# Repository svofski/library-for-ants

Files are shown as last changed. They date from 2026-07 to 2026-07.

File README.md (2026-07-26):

Library for ants
================
Robotic microSD card changer that wants to be a tape robot when it grows up

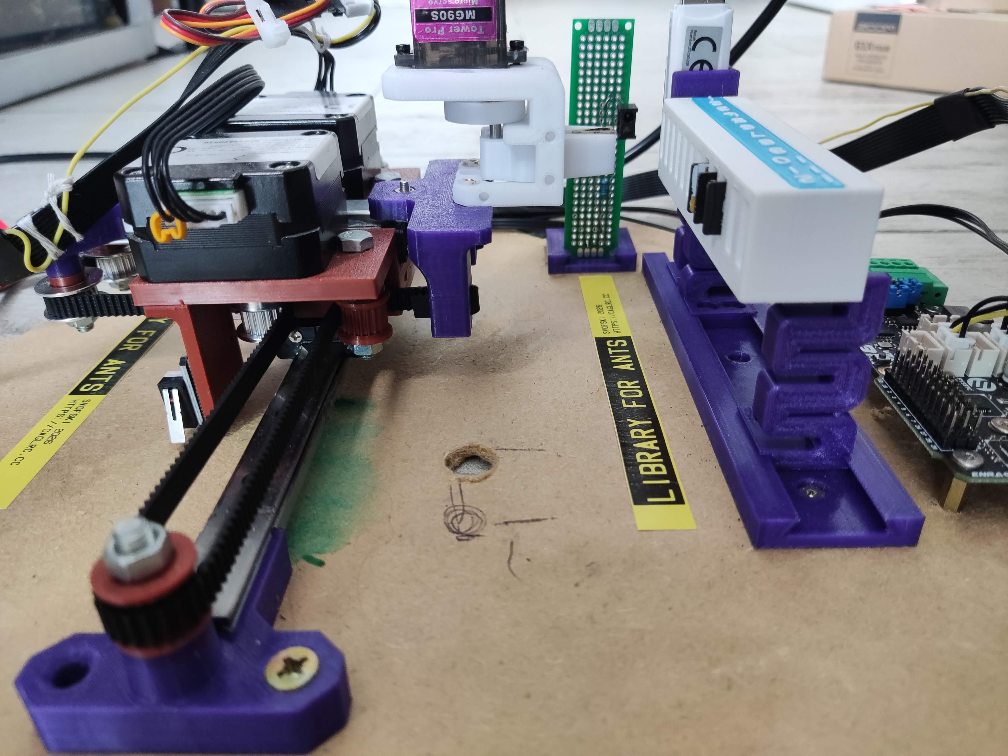
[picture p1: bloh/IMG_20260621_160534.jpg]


It's a microSD card changer. 

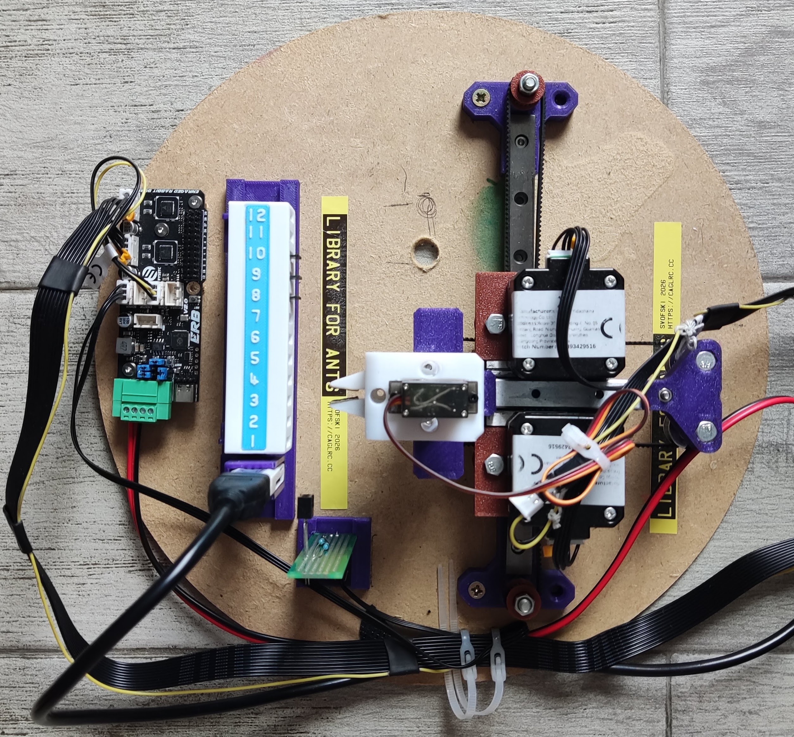
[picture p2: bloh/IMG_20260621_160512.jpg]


It can pick and insert one out of 12 cards in the magazine into a fixed microSD card reader.

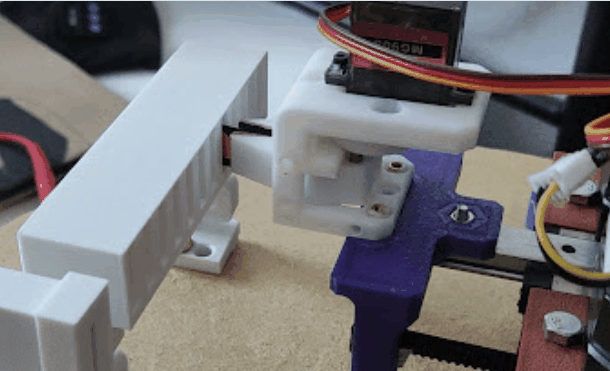
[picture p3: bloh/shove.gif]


The SD card is held using GRIPOR, which is an interesting project in itself.



GRIPOR
------
The gripper design files are [here](gripor)
There are two Gripors: the pliers version (used in Library for ants) and the parallel version. Both are tested and working.

Mechanics
---------
The mechanical parts are designed in FreeCAD. All CAD files are in the [cad](cad) folder.

Robotnik
--------
ERB firmware runs unmodified Klipper. The control program is written in Python using Textual. 
Some setup is needed to configure a fresh Linux to work with Klipper. 
The scripts are in the [scripts](scripts) directory. 

From experience, every distro needs a bit of persuasion them to work so they're only provided as hints.

Acknowledgements
----------------

**Library for ants** would not be possible without previous work of other people to whom I owe my deepest respect.

Links to other projects that I borrwed ideas from:
 * https://www.buildlog.net/blog/2017/10/the-midtbot-a-new-flavor-of-h-bot/
 * https://github.com/bdring/midTbot_esp32
 * https://www.klipper3d.org/
 * https://textual.textualize.io/

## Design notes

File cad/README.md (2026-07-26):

T-bot design files
==================

Printables
----------
All parts ready to print: [middleT-project.3mf](/cad/printables/middleT-project.3mf)

Design files
------------
FreeCAD doesn't make it easy to keep track of changes and interdependencies. I apologise if something is missing. 

Everything is built around linear rails with MGN12H blocks.

### X axis ends

End mount also functions as a physical stop for the Y axis when homing.

[xaxis-end.FCStd](xaxis-end.FCStd)

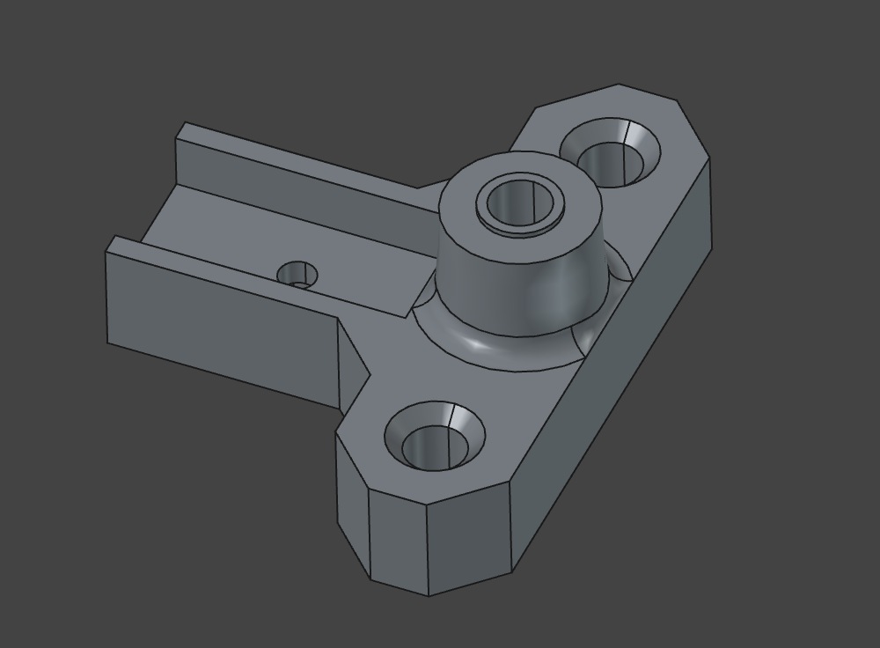
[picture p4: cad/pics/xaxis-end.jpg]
xaxis-end


### Y axis ends

The back side holds pulleys,

[yaxis-frontside.FCStd](yaxis-frontside.FCStd)

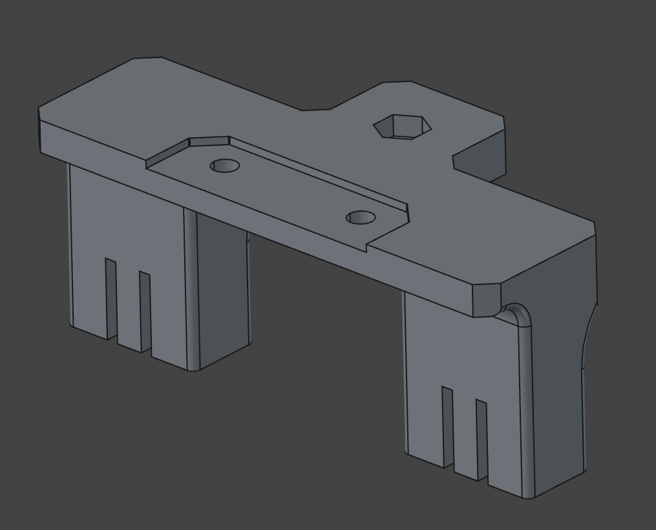
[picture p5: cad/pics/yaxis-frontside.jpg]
yaxis-frontside


[yaxis-backside-v2.FCStd](yaxis-backside-v2.FCStd)

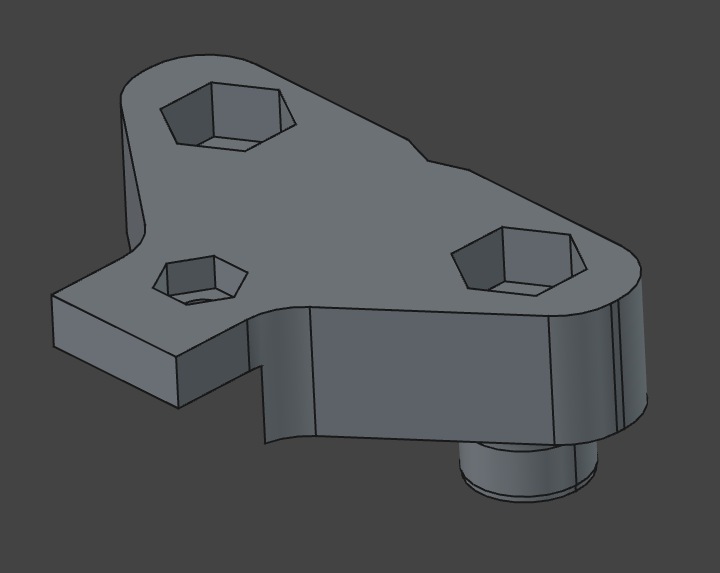
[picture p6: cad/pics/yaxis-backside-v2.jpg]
yaxis-backside-v2


### Middle T assembly

Middle T is a complex part that comprises two dovetailed pieces that ahold MGN12H sliders, two NEMA17 stepper motors and 2 additional pulleys.

[middlet-2.FCStd](middlet-2.FCStd)
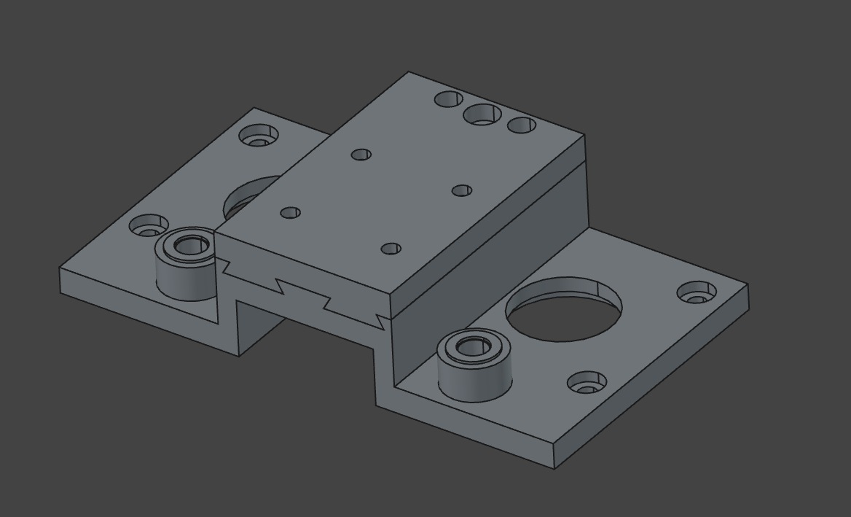
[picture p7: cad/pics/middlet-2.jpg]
middlet

(pictured upside down)

### Storage

This file has the magazine, magazine legs, usb reader leg and the bottom rail.

[usb-reader-adapter1.FCStd](usb-reader-adapter1.FCStd)

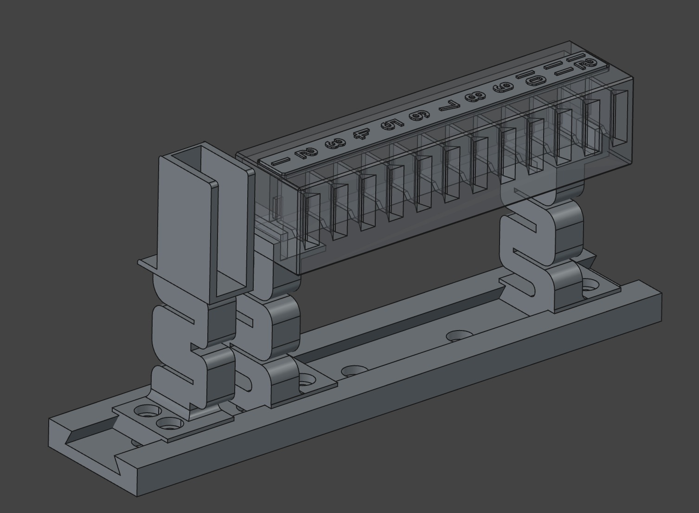
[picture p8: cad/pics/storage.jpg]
storage


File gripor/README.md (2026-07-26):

GRIPOR
======

Here you can find design files and printables for GRIPOR-pliers and GRIPOR-gears. 
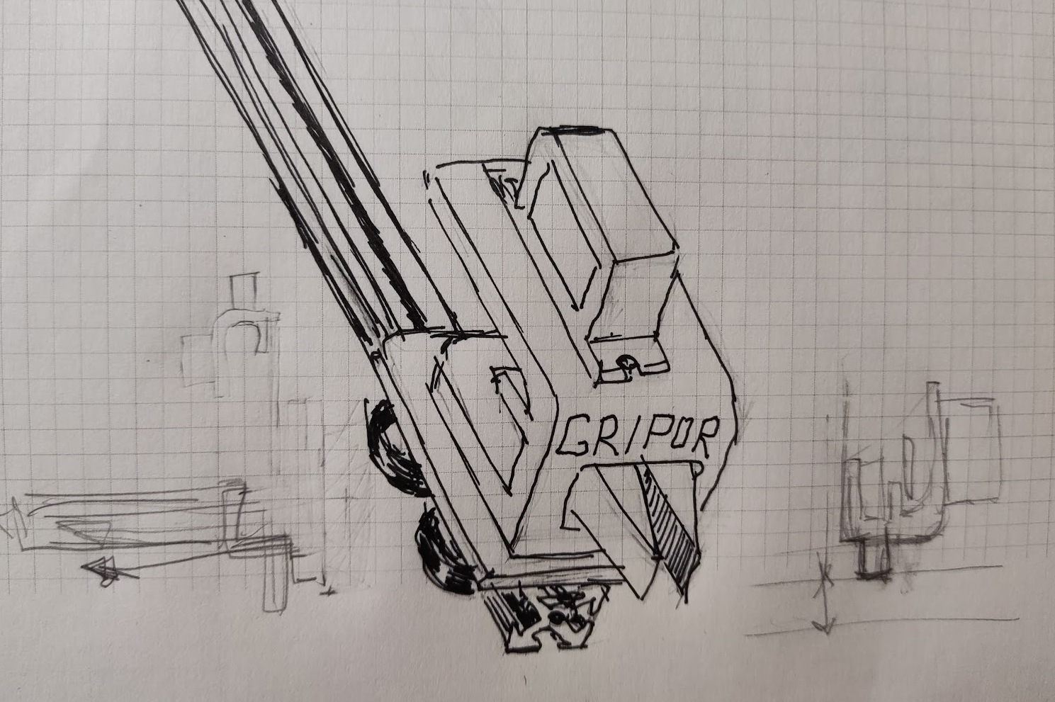
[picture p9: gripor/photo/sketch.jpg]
sketch


They can pinch and hold firmly small objects like microSD cards, or wield a small knife.

Pliers
------

This is the model that looks like a common sprue gripper.

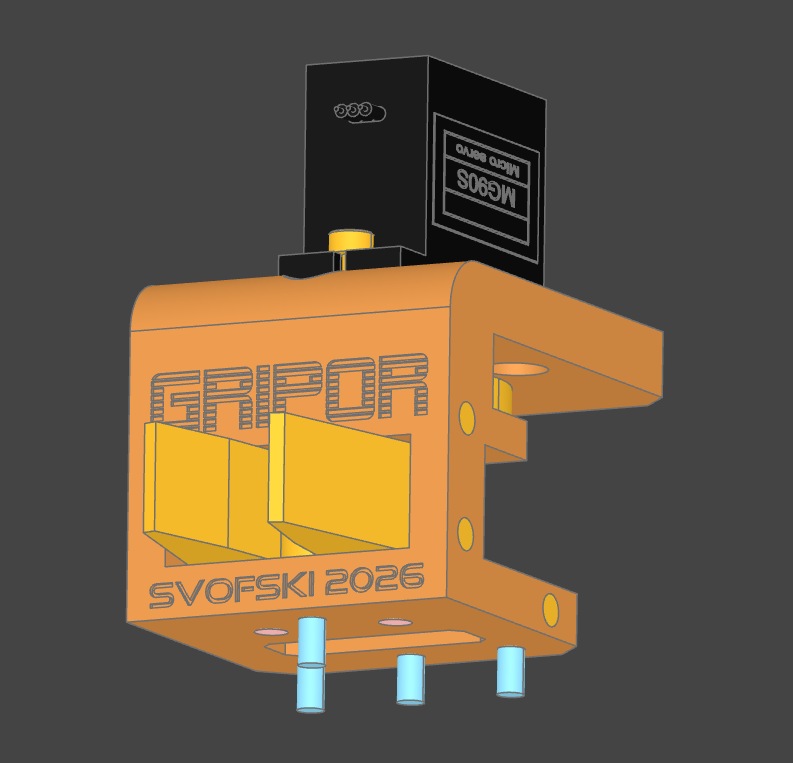
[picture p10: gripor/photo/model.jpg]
pliers-model

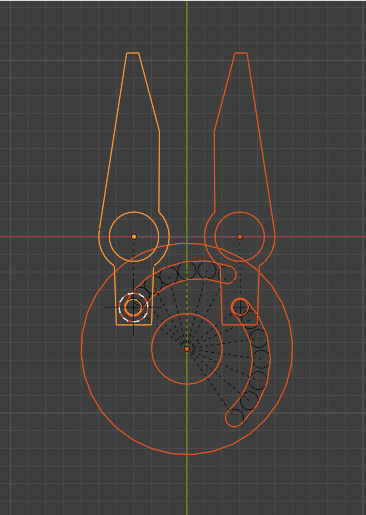
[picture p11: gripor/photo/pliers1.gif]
pliers-diagram

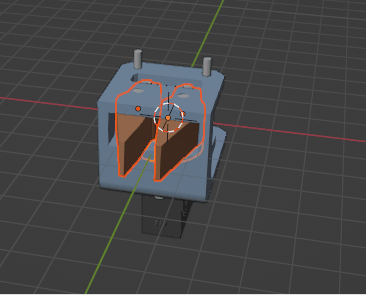
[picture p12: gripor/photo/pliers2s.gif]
pliers-3d


Extra hardware needed:

 * 4x bearings 3x6x2.5 (ID-OD-thickness)
 * 4x 3mm dia round pins approx 20mm long
 * 2xM2 screws for servo mount (optionally use M2 threaded inserts)
 * M3 threaded inserts optionally recommended for mounting holes
 * 1x MG90S micro servo

Some assembly required

Glue thin pieces of rubber eraser to the inner surfaces of the pliers' tips, it immensely improves the grip.

Gears
-----
This is a parallel gripper. It requires no extra hardware except for the screws. 
It's a good gripper that's easy to build, but it may be a bit less rigid than the pliers version.

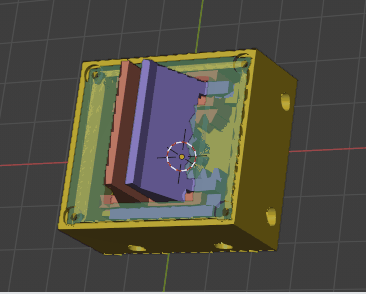
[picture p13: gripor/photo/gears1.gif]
gears-model


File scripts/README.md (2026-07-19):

## Environment setup stuff

### klipper & klippy

sudo apt install git python3-virtualenv python3-dev libffi-dev build-essential libncurses-dev gawk -y
git clone https://github.com/Klipper3d/klipper.git
virtualenv -p python3 ~/klippy-env
~/klippy-env/bin/pip install -r ~/library_for_ants/klipper/scripts/klippy-requirements.txt

### /etc/systemd/system/klipper.service

```
#Systemd service file for klipper
[Unit]
Description=Starts klipper on startup
After=network.target

[Install]
WantedBy=multi-user.target

[Service]
Type=simple
User=svo
RemainAfterExit=yes
ExecStart=/home/svo/klippy-env/bin/python /home/svo/library_for_ants/klipper/klippy/klippy.py /home/svo/library_for_ants/scripts/printer.cfg -l /tmp/klippy.log
Restart=always
RestartSec=10
```

```
sudo systemctl daemon-reload
sudo systemctl enable klipper.service
sudo systemctl start klipper.service
```

### Automount

I had very rough experience across Armbian and Debian. This seems to work on both:
```
sudo cp mnt-robot_media.* /etc/systemd/system/
sudo cp robot-media-watch.timer /etc/systemd/system/
sudo cp robot-media-watch.service /etc/systemd/system/
chmod +x robot-media-check.sh
mkdir /mnt/robot_media
systemctl daemon-reload 
systemctl enable --now mnt-robot_media.automount
systemctl enable --now robot-media-watch.timer
```

### udev hotplug 

Avoid annoying device name changes etc

```
sudo cp 99-klipper-hotplug.rules 99-usb-serial.rules /etc/udev/rules.d/
sudo udevadm control --reload-rules
```

### pythong

pip3 install -r requirements.txt

## References

Kinematics: midTbot

 https://www.buildlog.net/blog/2017/10/the-midtbot-a-new-flavor-of-h-bot/
 https://github.com/bdring/midTbot_esp32

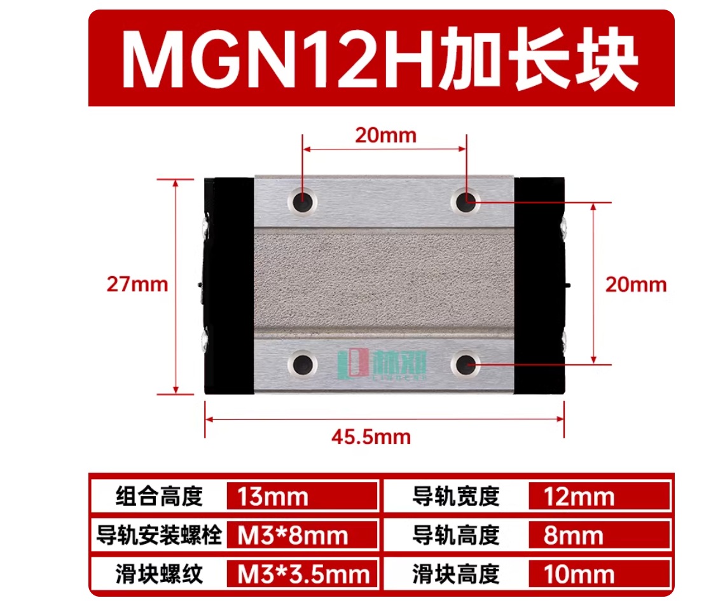
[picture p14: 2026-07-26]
cad/pics/mgn12h-block-dimensions.jpg

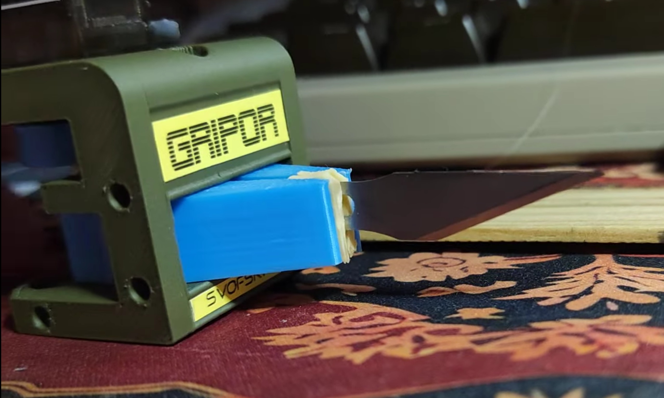
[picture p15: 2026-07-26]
bloh/gripor3.jpg

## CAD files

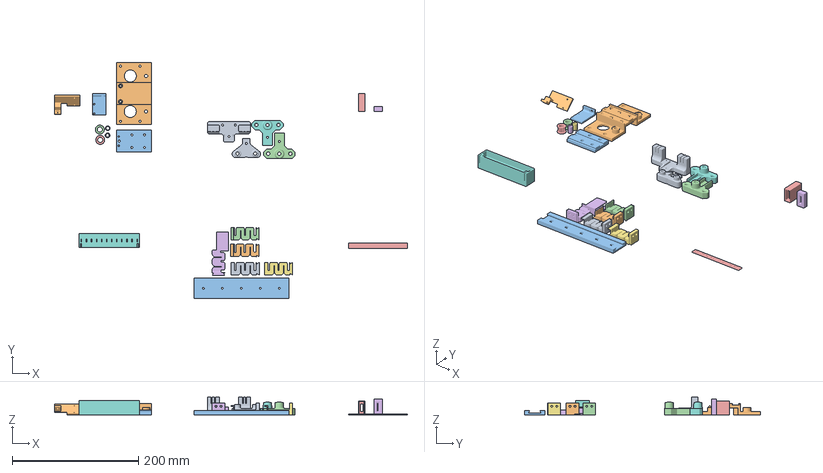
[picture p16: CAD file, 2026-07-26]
cad/printables/middleT-project.3mf
558.2 x 372.8 x 28.0 mm
yaxis-back
gt2-pulley-ID8.stl x 2
xaxis-end x 2
frontside
EndswitchBracketY.step
EndswitchBracketX.step
usb-reader-adapter1-middle-shell.step
usb-reader-adapter1-business-end.step
usb-reader-adapter1-post.step
storage-bay.step
storage-post-left.step
storage-post-right.step x 2
usb-reader-adapter1-storagerail.step
storageindex.step
usb-readerpost-for-vertical.step

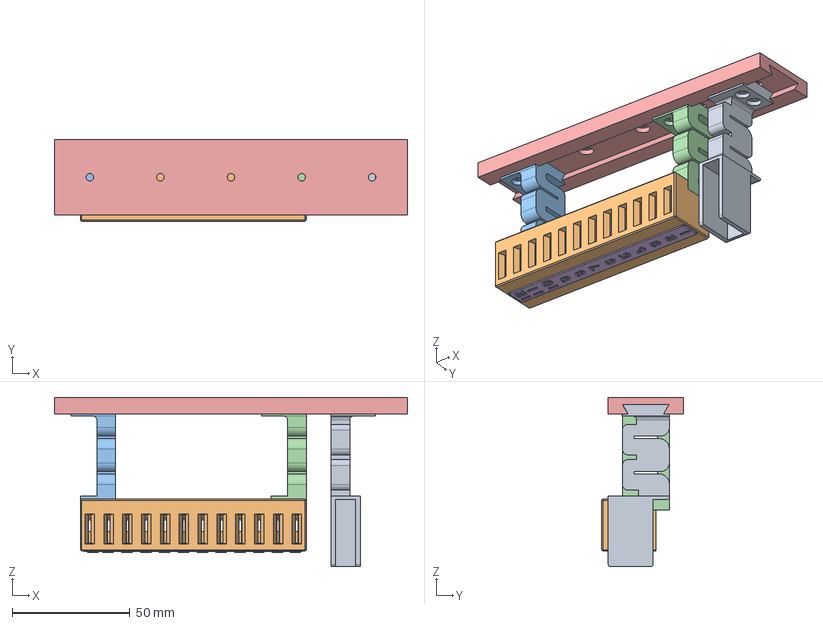
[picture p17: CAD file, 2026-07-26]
cad/usb-reader-adapter1.FCStd
150.0 x 34.7 x 72.0 mm
post-for-vertical
StorageBay
post-left
post-right
rail
index

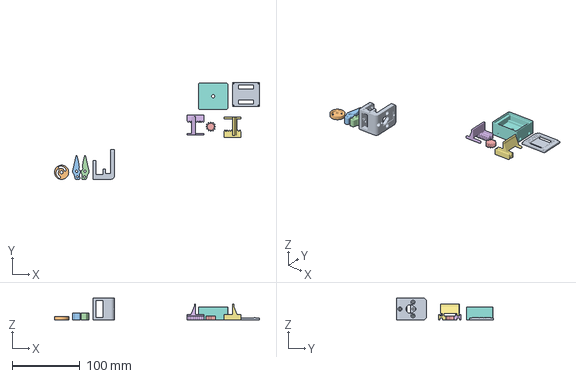
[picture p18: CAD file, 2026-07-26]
gripor/gripor-all.3mf
302.0 x 142.9 x 32.0 mm

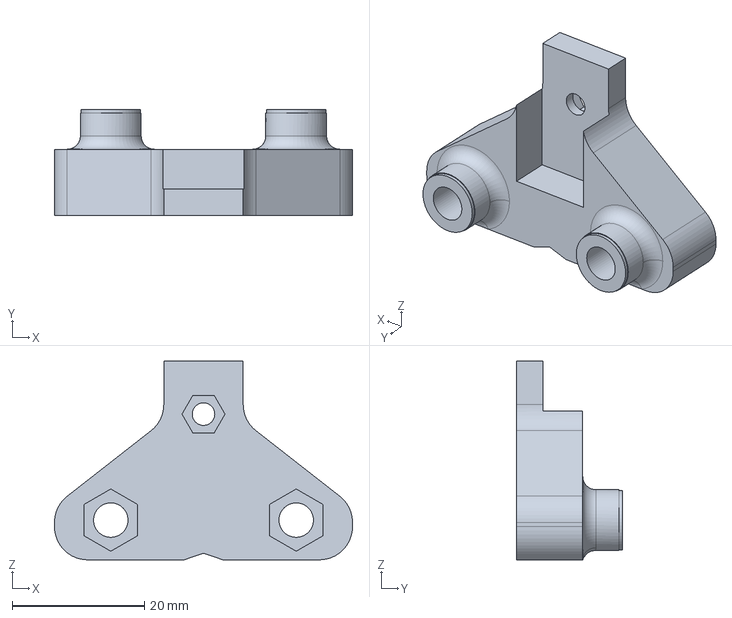
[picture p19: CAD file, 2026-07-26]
cad/yaxis-backside-v2.FCStd
45.0 x 16.0 x 30.0 mm

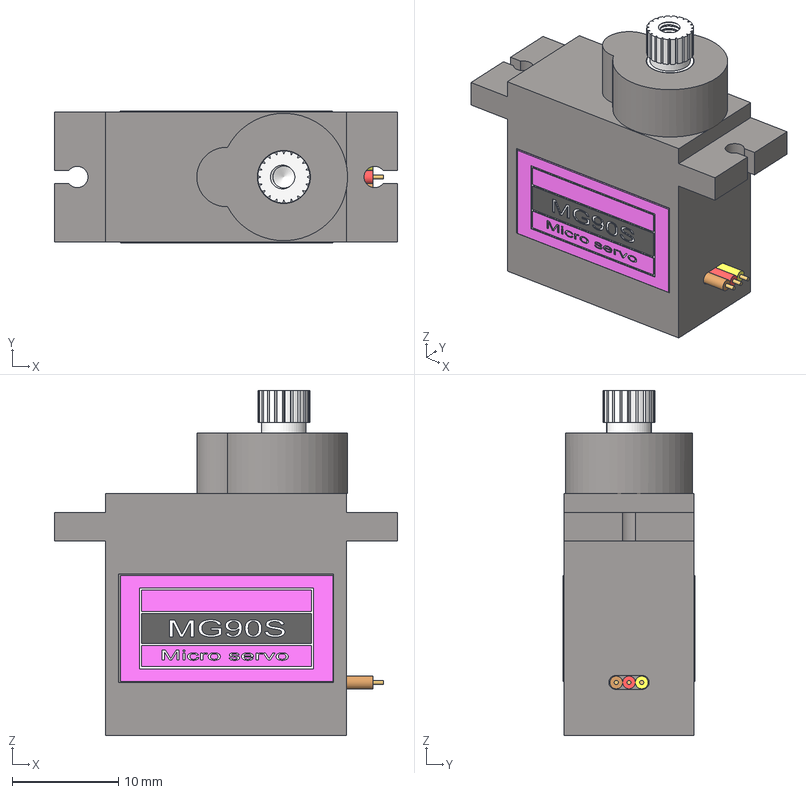
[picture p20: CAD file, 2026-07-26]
gripor/M90S_ali.step
32.3 x 12.4 x 32.5 mm
axe
base001
etiquette
Tube
Cylindre
Tube001
Tube002
etiquette001
Cylindre001
Cylindre002

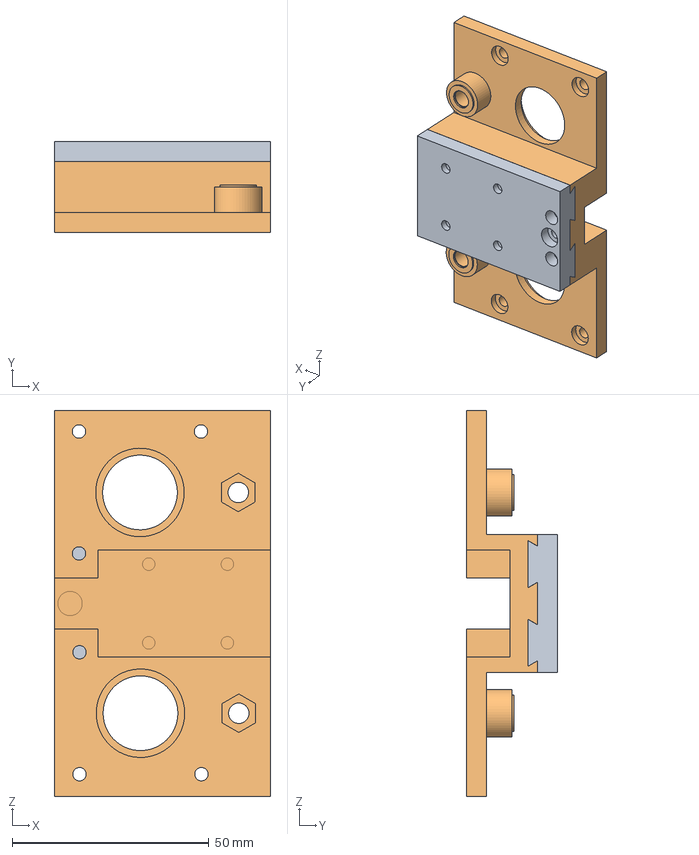
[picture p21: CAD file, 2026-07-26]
cad/middlet-2.FCStd
55.0 x 23.1 x 98.1 mm
MiddleTBottom
MiddleT-Compound

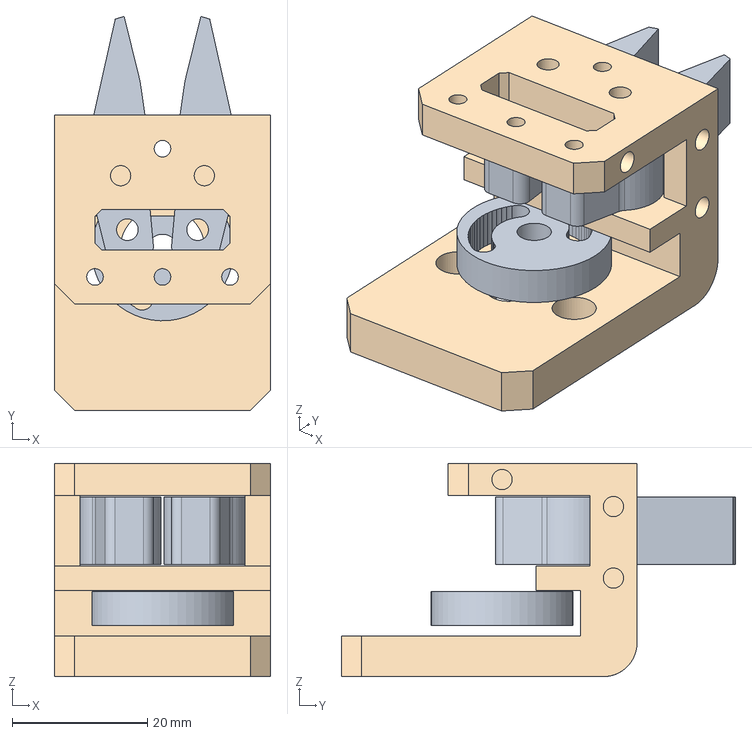
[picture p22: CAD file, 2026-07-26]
gripor/gripor-combined.step
32.0 x 58.4 x 31.6 mm

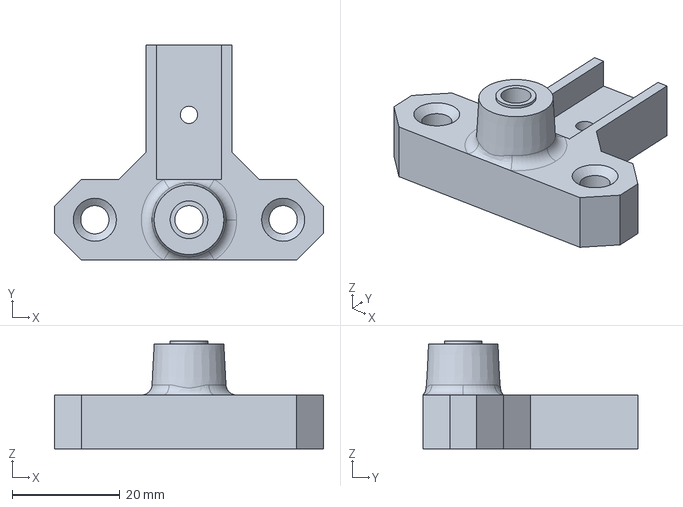
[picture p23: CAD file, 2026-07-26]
cad/xaxis-end.FCStd
50.0 x 40.0 x 20.0 mm

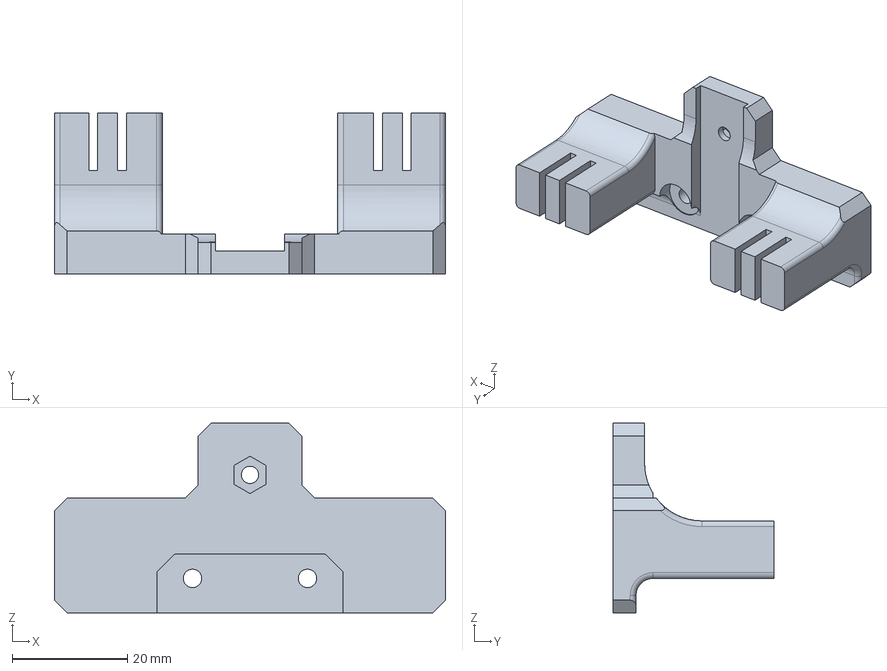
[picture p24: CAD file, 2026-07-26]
cad/yaxis-frontside.FCStd
68.0 x 28.0 x 33.0 mm

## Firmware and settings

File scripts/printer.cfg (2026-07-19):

[mcu]
serial: /dev/ttyERB

[printer]
kinematics: corexy
max_velocity: 300
max_accel: 800 #250
square_corner_velocity: 1
max_z_velocity: 10
max_z_accel: 100

[stepper_x]
step_pin: gpio10
dir_pin: gpio9
enable_pin: !gpio8
microsteps: 16
rotation_distance: 40
#endstop_pin: ^gpio24
position_endstop: 0
position_max: 210

# sensorless homing
endstop_pin: tmc2209_stepper_x:virtual_endstop
homing_speed: 35
homing_retract_dist: 0

[tmc2209 stepper_x]
uart_pin: gpio11
diag_pin: gpio13
run_current: 0.65
hold_current: 0.2
driver_SGTHRS: 70
stealthchop_threshold: 999999
interpolate: False

[stepper_y]
step_pin: gpio16
dir_pin: gpio15
enable_pin: !gpio14
microsteps: 16
rotation_distance: 40
#endstop_pin: ^gpio25
position_endstop: 0
position_max: 25
# sensorless homing
endstop_pin: tmc2209_stepper_y:virtual_endstop
homing_speed: 40
homing_retract_dist: 0

[tmc2209 stepper_y]
uart_pin: gpio17
diag_pin: gpio19
run_current: 0.65
hold_current: 0.2
driver_SGTHRS: 60
stealthchop_threshold: 999999
interpolate: False

# klipper can't live without z axis
[stepper_z]
step_pin: gpio18
dir_pin: gpio20
enable_pin: !gpio12
microsteps: 16
rotation_distance: 8
endstop_pin: gpio0
position_min: -1
position_max: 1
position_endstop: 0
homing_positive_dir: 0

[gcode_macro RESTORE_RUN_CURRENT]
gcode:
    SET_TMC_CURRENT STEPPER=stepper_x CURRENT={printer.configfile.settings['tmc2209 stepper_x'].run_current}
    SET_TMC_CURRENT STEPPER=stepper_y CURRENT={printer.configfile.settings['tmc2209 stepper_y'].run_current}

[homing_override]
gcode:
    GRIPOR_OPEN
    SET_TMC_CURRENT STEPPER=stepper_x CURRENT=0.2
    SET_TMC_CURRENT STEPPER=stepper_y CURRENT=0.3
    G4 P2000
    G28 Y
    G1 Y10 F1000
    G4 P1000
    G28 X
    G1 X50 F1000
    G90
    G1 Z0 F1000
    RESTORE_RUN_CURRENT
    RESPOND MSG="AXIS_STATUS: READY"
    RESPOND TYPE=echo MSG="macro_complete:homing"
axes: xy

[respond]
default_type: echo

[servo gripor_servo]
pin: gpio23
maximum_servo_angle: 180
minimum_pulse_width: 0.001000
maximum_pulse_width: 0.002400

#initial_angle: 0

# V-gripor
[gcode_macro GRIPOR_OPEN]
gcode:
    M400
    SET_SERVO SERVO=gripor_servo ANGLE=150
    M400

[gcode_macro GRIPOR_CLOSE]
gcode:
    M400
    SET_SERVO SERVO=gripor_servo ANGLE=75
    M400

[gcode_macro GRIPOR_10]
gcode:
    M400
    SET_SERVO SERVO=gripor_servo ANGLE=10
    M400

[gcode_macro GRIPOR_30]
gcode:
    M400
    SET_SERVO SERVO=gripor_servo ANGLE=30
    M400

[gcode_macro GRIPOR_60]
gcode:
    M400
    SET_SERVO SERVO=gripor_servo ANGLE=60
    M400

[gcode_macro GRIPOR_90]
gcode:
    M400
    SET_SERVO SERVO=gripor_servo ANGLE=90
    M400

[gcode_macro GRIPOR_120]
gcode:
    M400
    SET_SERVO SERVO=gripor_servo ANGLE=120
    M400

[gcode_macro GRIPOR_150]
gcode:
    M400
    SET_SERVO SERVO=gripor_servo ANGLE=150
    M400

[gcode_macro GRIPOR_180]
gcode:
    M400
    SET_SERVO SERVO=gripor_servo ANGLE=180
    M400

# parallel gripor
#[gcode_macro GRIPOR_OPEN]
#gcode:
#    M400
#    SET_SERVO SERVO=gripor_servo ANGLE=120
#    M400
#
#[gcode_macro GRIPOR_CLOSE]
#gcode:
#    M400
#    SET_SERVO SERVO=gripor_servo ANGLE=100
#    M400

[gcode_macro CHECK_HOMED]
gcode:
    {% set status = "" %}
    {% if 'x' in printer.toolhead.homed_axes %}
        {% set status = status ~ "X" %}
    {% endif %}
    {% if 'y' in printer.toolhead.homed_axes %}
        {% set status = status ~ "Y" %}
    {% endif %}
    
    {% if status == "XY" %}
        RESPOND MSG="AXIS_STATUS: READY"
    {% else %}
        RESPOND MSG="AXIS_STATUS: UNHOMED"
    {% endif %}

[filament_switch_sensor card_sensor]
pause_on_runout: False
switch_pin: !gpio25

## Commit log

2026-05-28 script adjusted for new storage bay
    [printer.cfg]
2026-05-30 separate logs for stuff and klipper
2026-05-31 library checker
    check without arguments iterates entire lib
    check 5 checks slot 5
    slots renumbered so that 12 is the leftmost
    push macro adjusted for loose-fit magazine
    [printer.cfg]
2026-06-01 patonki to mount and dismount
    patonki to click-check media presence, mount and dismount
    automount rules updated to timeout
2026-06-02 buttons, stuff
2026-06-03 detect klipper disconnection
    todo: detect klipper connection
2026-06-03 mount sequencing, quality improvements
2026-06-04 nice stuffs
    [printer.cfg]
2026-06-21 reader sdcard icon with num, dismount unknown supported
    - active reader icon with current card number display
    - dismount of unknown card searches for an empty slot
    experimented with parallel gripor, but it's dimensionally challenging so
    nah
    rubber lips work great. reduced Y extension by 1 mm
    [printer.cfg]
2026-06-22 autohoming before commands after powersave
    - homes automatically before commands after powersave
    - safety check of card in reader
    - multiple retries when retrieving the card from reader
    [printer.cfg]
2026-06-23 persistent state
    not sure if a good idea..
    also sometimes we enter endless homing loop somehow
2026-06-23 hopefully a more robust homing/rehoming routine
2026-07-19 moved to radxa, lots of wip
    updates to scripts: auto dismount works on debian where device is not
    reported as detached (timer poll thingy)
    tui updates directory after dismount
    [printer.cfg]
2026-07-25 adjustments for larger fonts or smaller windows
    perhaps the buttons have become more cryptic but meh
2026-07-26 3mf for the main robot
    [middleT-project.3mf]
2026-07-26 gripor files
    [M90S_ali.step, gripor-all.3mf, gripor-combined.step]
2026-07-26 tbot design files
    [middlet-2.FCStd, xaxis-end.FCStd, yaxis-backside-v2.FCStd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]
2026-07-26 storage design files
    [usb-reader-adapter1.FCStd]
2026-07-26 printabobel
    ...
2026-07-26 cad links
